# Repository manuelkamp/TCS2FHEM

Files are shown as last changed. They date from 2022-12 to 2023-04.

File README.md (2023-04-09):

# TCS2FHEM

If you have a TCS:Bus door intercom system and want to integrate it into your FHEM instance, this is a project for you. The goal of this project is to have a device, that connects the TCS:Bus intercom to FHEM. It should allow to trigger the dooropener and other functions (such as switching on the light) in FHEM. Also it should send events (like someone ringed the bell at the front door, or someone ringed the bell at the main door) to FHEM, so you can automate it (send notifications, interact...)  
## ATTENTION: THIS REPOSITORY IS A COPY AND WILL NOT BE UPDATED ON REGULAR BASIS. PLEASE GO TO https://git.kmpr.at/kamp/TCS2FHEM TO SEE THE LATEST CODE AND/OR SUBMIT PULL REQUESTS OR ISSUES!

## Hardware  
* [Raspberry Pico W](https://mk0.at/pico-w)  
* [Waveshare 2,23" OLED Display](https://mk0.at/waveshare-oled)  
* [4-Button Keypad](https://mk0.at/4-keypad)  
* PCB for your need (see kicad folder for examples)  
* 3D-printed Custom Case for Pico and Button Keypad and power circuit (see case_5v_PCB folder as an example)  

## Prereqisites
You need your PCB fully soldered with everything (you can use a Breadboard temporarily), including keypad and display. Load the Micropython firmware onto your Pico W. I used the v1.19.1-782-g699477d12 (2022-12-20).uf2. It is highly recommended to load the newest firmware from the official repository: https://micropython.org/download/rp2-pico-w/ - But you can use the one I used too, see firmware folder in this repository. Then upload all *.py files to the Pico W's root path (follow the instructions for configuration) and connect the TCS Bus lines accordingly. Finally plug in power (if not powered by TCS:Bus).

## Instructions/Setup
In the file configs.py set your configurations:  
country: your countrycode (AT=Austria, DE=Germany...) (2-digit string)  
ntp_host: set a ntp server (string url)  
gmt_offset: offset to gmt for your timezone in hours (int)  
auto_summertime: Enables changing to summertime (and back) automatically (True/False)  
disable_wifi_powersavingmode: Wifi powersavingmode is enabled per default. Set to true to disable powersavingmode for Wifi (True/False)  
api_port: Port on which the API is available (int)  
displayoff: Minutes after last action, display goes off automatically (int)  
log_incoming_bus_messages: Logs every incoming bus message, which is useful to find out relevant messages for initial setup (bool)  
log_housekeeping_days: Logfiles older than this value in days get deleted by housekeeping (int)  
frontdoor_ringing_message: The TCS:Bus message if someone rings the front door (list)  
door_ringing_message: The TCS:Bus message if someone rings the door (list)  
door_trigger_message: The TCS:Bus message to trigger the front door opener (list)  
light_trigger_message: The TCS:Bus message to trigger the light (list)  
tcs_message: The TCS:Bus message sent every 37 minutes from the TCS:Bus device to check devices - no action, just for filtering (list)  
api_client_ip: Only this IP is allowed to use the API. Leave blank to allow all connections from all IPs (string)  
fhem_door_ringed: URL of FHEM command, when the door is ringed (string)  
fhem_frontdoor_ringed: URL of FHEM command, when the front door is ringed (string)  

In the file secrets.py set your configurations:  
ssid: Wifi name (string)  
pw: Wifi password (string)  
api: API key (string)  

**Hint:** use `openssl rand -hex 20` to generate the api_key

## Wiring of Display  
```
OLED   =>    Pico  
VCC    ->    VSYS  
GND    ->    GND  
DIN    ->    11  
CLK    ->    10  
CS     ->    9  
DC     ->    8  
RST    ->    12  
SDA    ->    6  
SCL    ->    7   
```

## Wiring of 4-Button Keypad  
  

## Power circuit  
### Power from TCS Bus  
The power circuit allows you to run the Pico W directly from the TCS:Bus system's power. It also connects the bus to the Pico to read and write from it. The circuit files for KiCad are stored in the kicad subfolder 'power_from_tcs_bus' of this repo. You can order/print your own PCB with that files.  
  

### Power from 5V power source
The power circuit allows you to run the Pico W with a separate 5 Volt power source (f.e. a USB power adapter). It also connects the bus to the Pico to read and write from it. The circuit files for KiCad are stored in the kicad subfolder 'power_via_5v_source' of this repo. You can order/print your own PCB with that files.  
  

### Power from 9-24V power source
The power circuit allows you to run the Pico W with a separate power source from 9 Volt to 24 Volt. It also connects the bus to the Pico to read and write from it. The circuit files for KiCad are stored in the kicad subfolder 'power_via_9-24v_source' of this repo. You can order/print your own PCB with that files.  
  

## Networking  
Be sure that you give your Pico a static IP address on your router, so you know where the webservice is available and can set it up in FHEM.

## TCS2FHEM API  
You can configure the port, on which the API runs in configs.py in the 'api_port'-value. You also have to set an API-Key in secrets.py in the 'api'-value. Then you can call the API as follows:  
http://servername/api_key/command[/json]  

You can use the following commands:  
triggerdoor - Triggers the front door opener  
triggerlight - Triggers the light  
togglepartymode - Enables/disables the Party-Mode  
partymodeon - Sets Party-Mode enabled  
partymodeoff - Sets Party-Mode disabled  
partymodestate - Returns the state of the Party-Mode  
ping - Check if the API is up and running  
stats - Returns some stats of the device  
reboot - Reboots the device  
ringdoor - Sends "ring doorbell" message to TCS:Bus  
ringfrontdoor - Sends "ring front doorbell" message to TCS:Bus  

## FHEM API  

With the FHEM API you interconnect your FHEM instance with your TCS2FHEM device. It allows you for example control the door trigger via FHEM, or handle incoming TCS:Bus messages within FHEM to send you a notification or anything else. In this example configuration, we set up a HTTPMOD device in FHEM to control your TCS2FHEM device within FHEM, using the above explained API commands.  

### Example Setup of FHEMWEB

You need to give your TCS2FHEM device a static IP address within your network. Then you need to create a new FHEMWEB and configure it to work only with the static IP of your TCS2FHEM device without the csrfToken.  

```
define WEBapi FHEMWEB 8086 global
attr WEBapi csrfToken none
attr WEBapi allowfrom your-TCS2FHEM-static-IP|127.0.0.1
```

### Exampe of a HTTPMOD device in FHEM to control TCS2FHEM

This device is used to trigger actions from FHEM via the TCS2FHEM API. In this Example you can trigger the dooropener, the light and the builtin partymode of the TCS2FHEM device.  

```
define TCS2FHEM HTTPMOD 0
setuuid TCS2FHEM 63b875f4-f33f-1b7d-61d3-9101ee190fa5bae1
attr TCS2FHEM icon Todoist
attr TCS2FHEM room TCS
attr TCS2FHEM set01Name triggerDoor
attr TCS2FHEM set01NoArg 1
attr TCS2FHEM set01URL http://servername/api_key/triggerdoor
attr TCS2FHEM set02Name triggerLight
attr TCS2FHEM set02NoArg 1
attr TCS2FHEM set02URL http://servername/api_key/triggerlight
attr TCS2FHEM set03Name togglePartyMode
attr TCS2FHEM set03NoArg 1
attr TCS2FHEM set03URL http://servername/api_key/togglepartymode
attr TCS2FHEM webCmd triggerDoor:triggerLight:togglePartyMode
```

### Example of Notify and Dummy device in FHEM to send a message to your smartphone

This dummy device is used to represent the state. The state 'idle' means, there is no action. The state 'ringed' is set if someone rings your doorbell and the TCS2FHEM device sets it. The notify device in FHEM is used to see the change from idle to ringed, and you can perform your wanted action in FHEM.  

```
define TCS_Door dummy
setuuid TCS_Door 63a1c02e-f33f-1b7d-29b2-21917943a9d12101
attr TCS_Door room TCS
attr TCS_Door setList idle ringed
```

```
define n_TCS_Door notify TCS_Door:ringed set Talk msg Jemand hat an der Wohnungstür angeläutet;; set TCS_Door idle
setuuid n_TCS_Door 63a1c0c2-f33f-1b7d-fe89-1e89dde293580eb1
attr n_TCS_Door disabledAfterTrigger 10
attr n_TCS_Door room TCS
```

For this devices, the FHEM API Url that you need to use in TCS2FHEM setting 'fhem_door_ringed' would be:  
```
http://fhem-server:8086/fhem?cmd=set%20TCS_Door%20ringed&XHR=1
```

This works exactly the same for the TCS2FHEM settings 'fhem_frontdoor_ringed'.

### Example of Notify and Dummy device in FHEM for Partymode

If you decide to not use the builtin Partymode in your TCS2FHEM device, you can set up a Partymode in FHEM. This may be useful, if you want to trigger more actions as it would be possible with just the TCS2FHEM device.  

```
coming soon...
``` 

## Legal remarks
I am not affiliated to TCSAG and/or any of their brands and/or trademarks, nor do I have any business information on the proprietary TCS:Bus. I just reverse engineered it, to include my intercom system into my home automation and shared my research here. All Rights to the possible Trademark TCS:Bus and all things connected, remain untouched by this open source project.

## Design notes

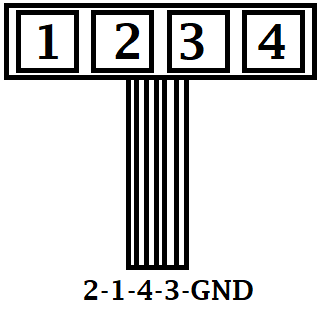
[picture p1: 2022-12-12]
docs/4-key-pad-connector.png

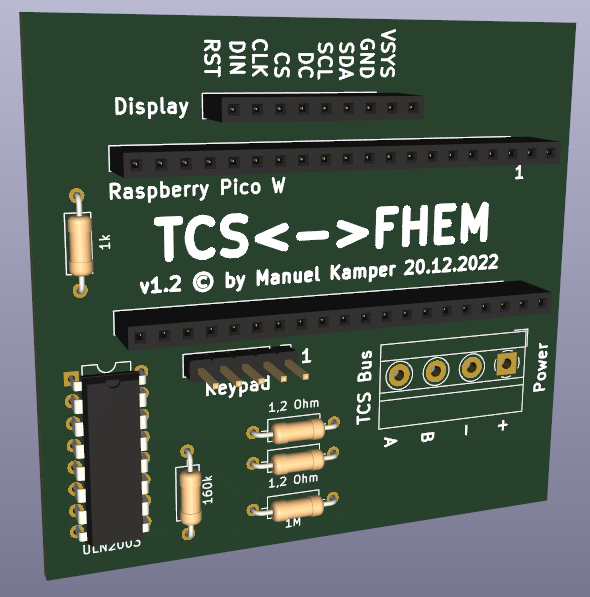
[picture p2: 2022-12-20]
docs/pico_tcs_5v.png

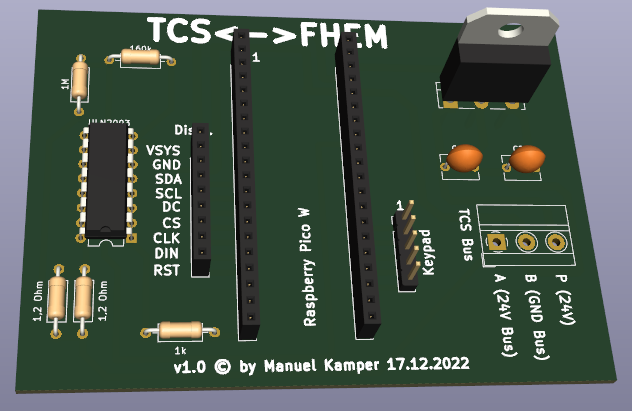
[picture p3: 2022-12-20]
docs/pico_tcs_bus.png

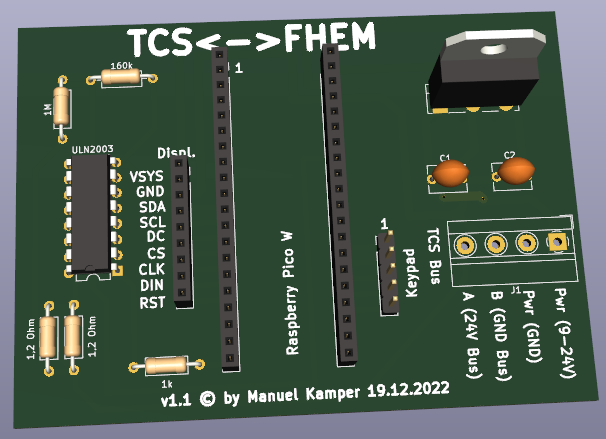
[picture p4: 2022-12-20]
docs/pico_tcs_9-24v.png

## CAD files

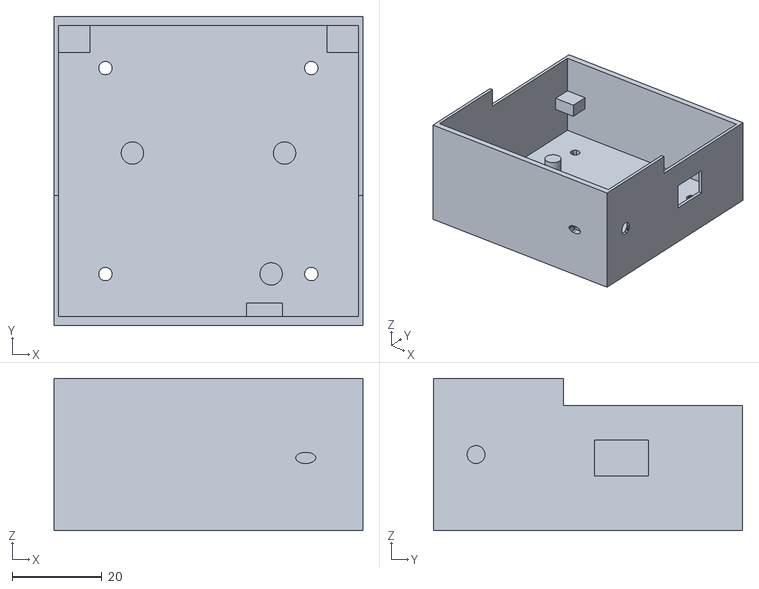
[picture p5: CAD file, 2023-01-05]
case_5v_PCB/case_base.stl
69.0 x 69.0 x 34.0

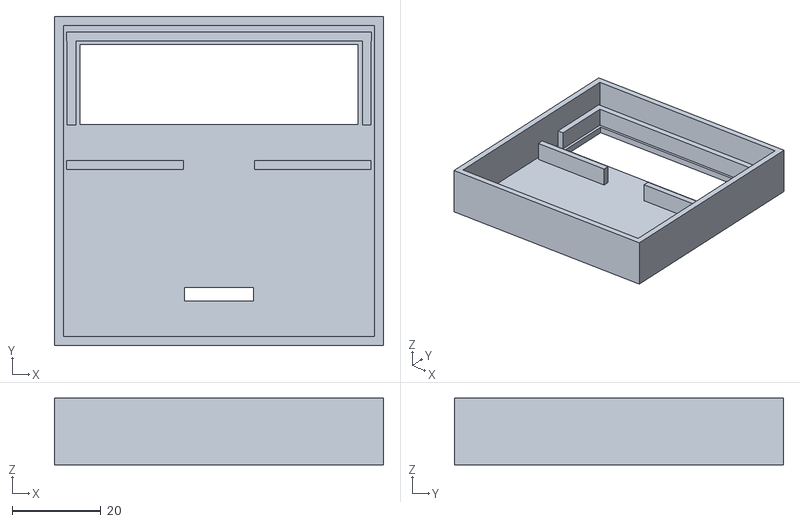
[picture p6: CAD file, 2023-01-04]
case_5v_PCB/case_plate.stl
74.0 x 74.0 x 15.0

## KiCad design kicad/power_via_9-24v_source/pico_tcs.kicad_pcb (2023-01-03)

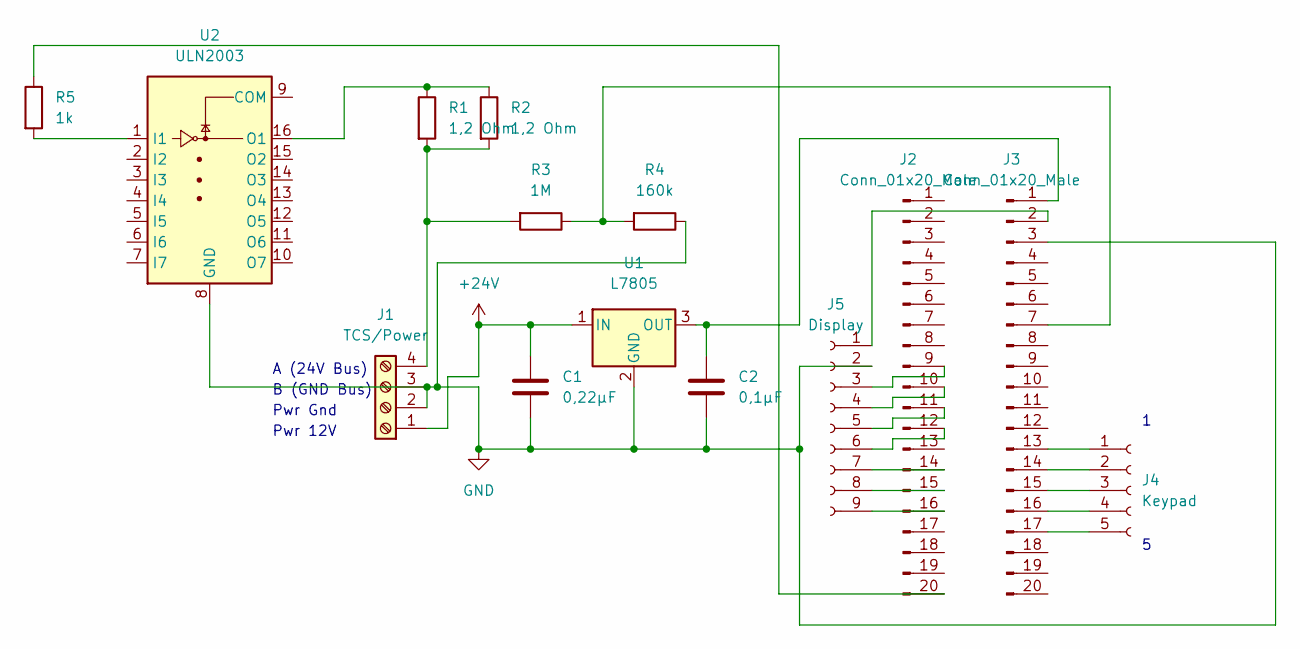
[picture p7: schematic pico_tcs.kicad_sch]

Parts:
C1: 0,22µF; C_Disc_D6.0mm_W4.4mm_P5.00mm
C2: 0,1µF; C_Disc_D6.0mm_W4.4mm_P5.00mm
J1: TCS/Power; TerminalBlock_MetzConnect_Type011_RT05504HBWC_1x04_P5.00mm_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
J2, J3: Conn_01x20_Male; PinSocket_1x20_P2.54mm_Vertical
J4: Keypad; PinHeader_1x05_P2.54mm_Vertical
J5: Display; PinSocket_1x09_P2.54mm_Vertical
R1, R2: 1,2 Ohm; R_Axial_DIN0207_L6.3mm_D2.5mm_P10.16mm_Horizontal
R3: 1M; R_Axial_DIN0207_L6.3mm_D2.5mm_P10.16mm_Horizontal
R4: 160k; R_Axial_DIN0207_L6.3mm_D2.5mm_P10.16mm_Horizontal
R5: 1k; R_Axial_DIN0207_L6.3mm_D2.5mm_P10.16mm_Horizontal
U1: L7805; TO-218-3_Vertical
U2: ULN2003; DIP-16_W7.62mm

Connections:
+24V: C1.1, J1.1, U1.1 (IN)
GND: C1.2, C2.2, J1.2, J1.3, J3.3, J5.2, R4.1, U1.2 (GND), U2.8 (GND)
unnamed: C2.1, J3.1, U1.3 (OUT)
unnamed: J1.4, R1.2, R2.2, R3.2
unnamed: J2.9, J5.3
unnamed: J2.10, J5.4
unnamed: J2.11, J5.5
unnamed: J2.12, J5.6
unnamed: J2.14, J5.7
unnamed: J2.15, J5.8
unnamed: J2.16, J5.9
unnamed: J2.20, R5.1
unnamed: J3.2, J5.1
unnamed: J3.7, R3.1, R4.2
unnamed: J3.13, J4.1
unnamed: J3.14, J4.2
unnamed: J3.15, J4.3
unnamed: J3.16, J4.4
unnamed: J3.17, J4.5
unnamed: R1.1, R2.1, U2.16 (O1)
unnamed: R5.2, U2.1 (I1)

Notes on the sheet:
Pwr Gnd
Pwr 12V
A (24V Bus)
B (GND Bus)

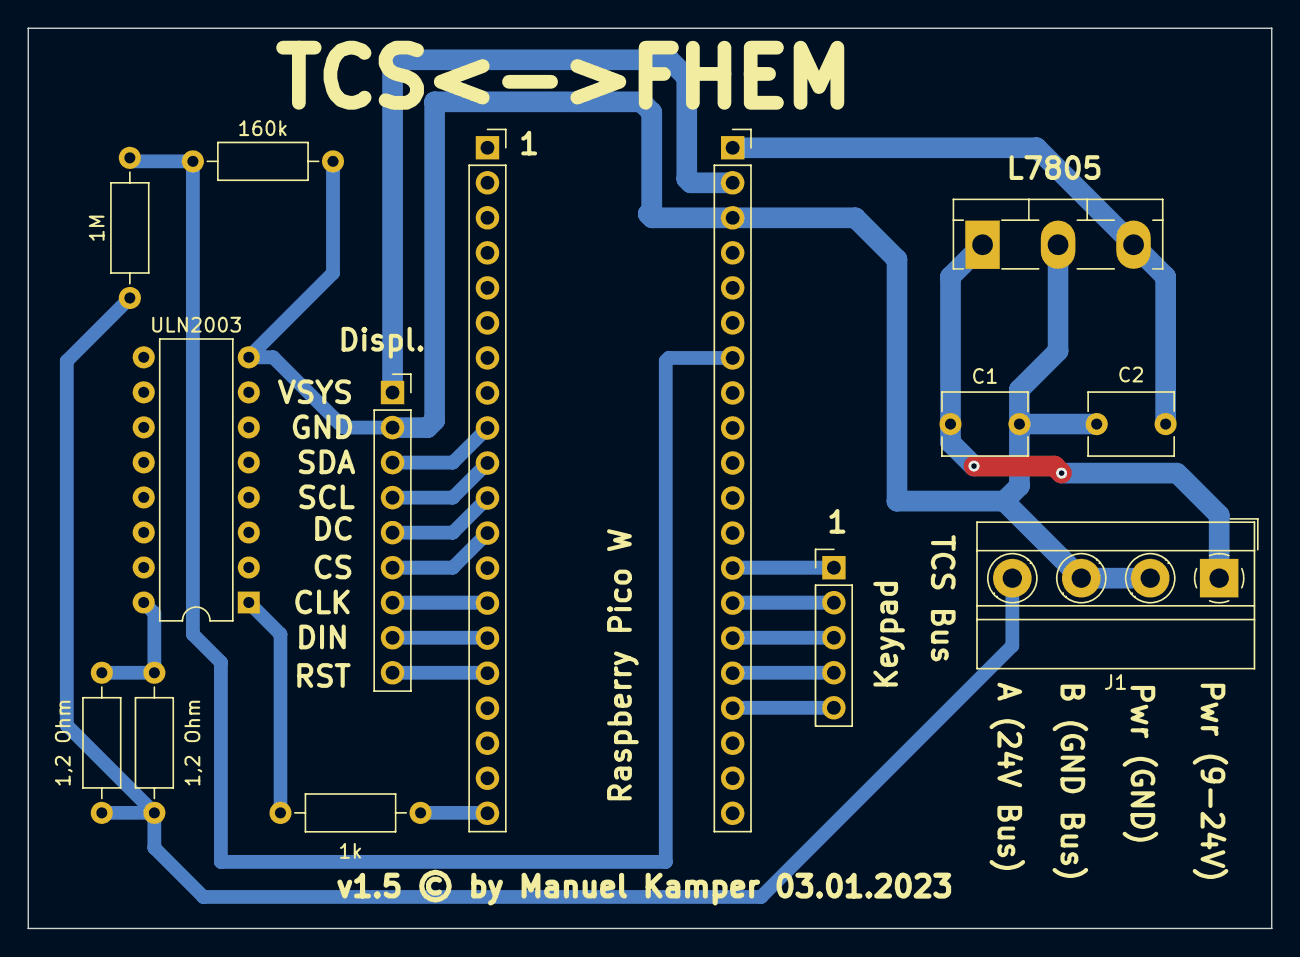
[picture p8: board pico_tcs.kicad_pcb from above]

Board: 2 copper layers, 90.2 x 65.3 mm, 14 parts (0 on the bottom side), 21 nets.

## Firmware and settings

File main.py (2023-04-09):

import rp2
import TimeUtils
import Logger
import Oled
import Networking
import NTP
import uasyncio as asyncio
import utime as time
import Keypad
import usocket as socket
import urequests as requests
from machine import ADC, Pin

from secrets import secrets
from configs import configs

rp2.country(configs['country'])
version = "0.9-beta"

Oled = Oled.Oled()
TimeUtils = TimeUtils.TimeUtils()
Logger = Logger.Logger(configs['log_housekeeping_days'])
Networking = Networking.Networking(Logger, secrets['ssid'], secrets['pw'])
NTP = NTP.NTP(Logger)
Keypad = Keypad.Keypad()

boottime = time.time()
lastActionTicks = 0
subscreen = 0
sc = 0
partyMode = False
displayOff = False
busline = ADC(28)
triggerline = Pin(15, Pin.OUT)
writerActive = False

# Checks if string is integer
def IsInt(possibleint):
    try:
        int(possibleint)
    except:
            return False
    else:
            return True

# Reboots the Pico W (f.e. in case of an error)
def Reboot():
    Logger.LogMessage("Performing Reboot")
    machine.reset()

# Calculates the uptime in hours and minutes
def Uptime():
    global boottime
    seconds = (time.time() - boottime) % (24 * 3600)
    hours = seconds // 3600
    seconds %= 3600
    minutes = seconds // 60
    seconds %= 60
    return "%d:%02d" % (hours, minutes)

# Shows text on the display
def ShowText(line1, line2, line3):
    Oled.fill(0x0000)
    Oled.text(line1,1,2,Oled.white)
    Oled.text(line2,1,12,Oled.white)
    Oled.text(line3,1,22,Oled.white)  
    Oled.show()

# Main method for display output
heartbeat = "H"
def BuildScreen():
    global subscreen, partyMode, lastActionTicks, displayOff, heartbeat
    if heartbeat == "H":
        heartbeat = " "
    else:
        heartbeat = "H"
    lastActionTicks += 1
    # after 10 Seconds of no activity, go back to main screen
    if (lastActionTicks >= 20):
        subscreen = 0
    # after X Minutes turn off the display
    if (lastActionTicks >= (configs['displayoff'] * 60 * 2)):
        displayOff = True
        ShowText("","","")
    else:
        if (subscreen == 0):
            ShowText("TCS<->FHEM " + PartyModeActive() + " " + Networking.IsWifiConnected() + " " + heartbeat + "", TimeUtils.DateTimeNow(), "Auf LiG PaM Chk")
        elif (subscreen == 1):
            ShowText("Eingangstuer", "getriggert", "            Ext")
        elif (subscreen == 2):
            ShowText("Licht am Gang", "getriggert", "            Ext")
        elif (subscreen == 3):
            ShowText("Party-Mode", ("aktiviert" if partyMode else "deaktiviert"), "            Ext")
        elif (subscreen == 4):
            ShowText("Hostname:", configs['hostname'], "Up  Dwn     Ext")
        elif (subscreen == 5):
            ShowText("MAC Address:", Networking.GetMACAddress(), "Up  Dwn     Ext")
        elif (subscreen == 6):
            ShowText("IP Address:", Networking.GetIPAddress(), "Up  Dwn     Ext")
        elif (subscreen == 7):
            ShowText("API key:", secrets['api'], "Up  Dwn     Ext")
        elif (subscreen == 8):
            ShowText("CPU Frequency:", str(machine.freq()/1000000) + " MHz", "Up  Dwn     Ext")
        elif (subscreen == 9):
            ShowText("Firmware vers.:", version, "Up  Dwn     Ext")
        elif (subscreen == 10):
            ShowText("Uptime (H:m):", Uptime(), "Up  Dwn     Ext")
        elif (subscreen == 11):
            ShowText("Perform", "reboot now", "Up  Dwn OK  Ext")
        else:
            ShowText("Error","Invalid Screen", "            Ext")

# Helper-method for the systemcheck-output on the display
def ShowSystemCheck(screen):
    global subscreen, sc
    if (screen == "start"):
        Logger.LogMessage("Showing Systemcheck")
        sc = 0
    elif (screen == "next"):
        sc = sc + 1
    else:
        sc = sc - 1
    if (sc > 7):
        sc = 0
    elif (sc < 0):
        sc = 7
    subscreen = sc + 4

# Activates/deactivates the party-mode
def TogglePartyMode():
    global subscreen, partyMode
    if (partyMode):
        partyMode = False
        ExternalAPI("partymode" + PartyModeState())
        Logger.LogMessage("Party-Mode off")
    else:
        partyMode = True
        ExternalAPI("partymode" + PartyModeState())
        Logger.LogMessage("Party-Mode on")
    subscreen = 3

# Sets the party-mode active/inactive
def SetPartyMode(newValue):
    global partyMode
    partyMode = newValue
    ExternalAPI("partymode" + PartyModeState())
    Logger.LogMessage("Setting Party-Mode via API to " + PartyModeState())

# Returns status of party-mode
def PartyModeState():
    global partyMode
    if (partyMode):
        return "enabled"
    else:
        return "disabled"

# Returns status symbol if party-mode is active
def PartyModeActive():
    global PartyMode
    if (partyMode):
        return "P"
    else:
        return " "

#####################################################################

# Helper-method to allow error handling and output in asyncio
def set_global_exception():
    def handle_exception(loop, context):
        Logger.LogMessage("Fatal error: " + str(context["exception"]))
        import sys
        sys.print_exception(context["exception"])
        sys.exit()
        Reboot()
    loop = asyncio.get_event_loop()
    loop.set_exception_handler(handle_exception)

# Main method for all the UI-handling
async def UiHandling():
    global interrupt_flag, lastActionTicks, displayOff, subscreen
    Logger.LogMessage("UI handling started")
    while True:
        BuildScreen()
        if Keypad.interrupt_flag is 1:
            Keypad.interrupt_flag = 0
            lastActionTicks = 0
            if (displayOff):
                displayOff = False
            else:
                Keypad.interrupt_flag = 0
                if (subscreen == 0):
                    if (Keypad.tastePressed == Keypad.taste1):
                        ShowSystemCheck("start")
                    elif (Keypad.tastePressed == Keypad.taste2):
                        TogglePartyMode()
                    elif (Keypad.tastePressed == Keypad.taste3):
                        subscreen = 2
                        Logger.LogMessage("Triggering Licht")
                        await TCSBusWriter(configs['light_trigger_message'])
                    elif (Keypad.tastePressed == Keypad.taste4):
                        subscreen = 1
                        Logger.LogMessage("Triggering Door")
                        await TCSBusWriter(configs['door_trigger_message'])
                    else:
                        Logger.LogMessage("Error: Invalid Button pressed!")
                elif (subscreen == 1 or subscreen == 2 or subscreen == 3):
                    if (Keypad.tastePressed == Keypad.taste1):
                        subscreen = 0
                elif (subscreen == 4 or subscreen == 5 or subscreen == 6 or subscreen == 7 or subscreen == 8 or subscreen == 9 or subscreen == 10 or subscreen == 11):
                    if (Keypad.tastePressed == Keypad.taste1):
                        subscreen = 0
                    elif (subscreen == 11 and Keypad.tastePressed == Keypad.taste2):
                        Reboot()
                    elif (Keypad.tastePressed == Keypad.taste3):
                        ShowSystemCheck("next")
                    elif (Keypad.tastePressed == Keypad.taste4):
                        ShowSystemCheck("prev")
                    else:
                        Logger.LogMessage("Error: Invalid Button pressed!")
                else:
                    if (Keypad.tastePressed == Keypad.taste1):
                        subscreen = 0
        await asyncio.sleep(0.5)

# Main method for the API
html = """<!DOCTYPE html>
<html>
    <head> <title>TCS<->FHEM</title> </head>
    <body> <h1>TCS<->FHEM</h1>
        <p>%s</p>
    </body>
</html>"""
json = """{ "TCS<->FHEM API":"%s" }"""
async def APIHandling(reader, writer):
    request_line = await reader.readline()
    while await reader.readline() != b"\r\n":
        pass
    request = str(request_line)
    try:
        request = request.split()[1]
    except IndexError:
        pass
    client_ip = writer.get_extra_info('peername')[0]
    Logger.LogMessage("API request: " + request + " - from client IP: " + client_ip)
    if (configs['api_client_ip'] != "") and (configs['api_client_ip'] != client_ip):
        Logger.LogMessage("Unauthorized client! Aborting API Handling now.")
        stateis = "<b>Error 401:</b> Client '" + client_ip + "' is not authorized to use the API!<br><br>Set authorized client IP in configs.py!"
        response = html % stateis
        writer.write('HTTP/1.0 401 Unauthorized\r\nContent-type: text/html\r\n\r\n')
    else:
        req = request.split('/')
        stateis = ""
        if (len(req) == 3 or len(req) == 4 or len(req) == 5):
            if (req[1] == secrets['api']):
                if (req[2] == "triggerdoor"):
                    Logger.LogMessage("Triggering Door")
                    await TCSBusWriter(configs['door_trigger_message'])
                    stateis = "Triggered front door opener"
                elif (req[2] == "triggerlight"):
                    Logger.LogMessage("Triggering Licht")
                    await TCSBusWriter(configs['light_trigger_message'])
                    stateis = "Triggered light"
                elif (req[2] == "togglepartymode"):
                    TogglePartyMode()
                    stateis = "Toggled Party-Mode"
                elif (req[2] == "partymodeon"):
                    SetPartyMode(True)
                    stateis = "Enabled Party-Mode"
                elif (req[2] == "partymodeoff"):
                    SetPartyMode(False)
                    stateis = "Disabled Party-Mode"
                elif (req[2] == "partymodestate"):
                    stateis = "Party-Mode is " + PartyModeState()
                elif (req[2] == "ping"):
                    stateis = "OK"
                elif (req[2] == "stats"):
                    stateis = "IP address: " + Networking.GetIPAddress() + "<br>MAC address: " + Networking.GetMACAddress() + "<br>Hostname: " + configs['hostname'] + "<br>API Port: " + str(configs['api_port']) + "<br>Uptime (h:m): " + Uptime() + "<br>Date/Time: " + TimeUtils.DateTimeNow() + "<br>Version: " + version + "<br>GMT Timezone Offset (hours): " + str(configs['gmt_offset']) + "<br>Auto summertime: " + str(configs['auto_summertime']) + "<br>Display off time (mins): " + str(configs['displayoff']) + "<br>Log incoming bus messages: " + str(configs['log_incoming_bus_messages']) + "<br>Housekeep logfiles after days: " + str(configs['log_housekeeping_days']) + "<br>Message 'Front door ringing': " + str(configs['frontdoor_ringing_message']) + "<br>Message 'Door ringing': " + str(configs['door_ringing_message']) + "<br>Message 'Door opener triggered': " + str(configs['door_trigger_message']) + "<br>Message 'Light triggered': " + str(configs['light_trigger_message']) + "<br>CPU frequency (MHz): " + str(machine.freq()/1000000)
                elif (req[2] == "reboot"):
                    stateis = "Rebooting device now..."
                    Reboot()
                elif (req[2] == "ringdoor"):
                    stateis = "Ringing doorbell"
                    await TCSBusWriter(configs['door_ringing_message'])
                elif (req[2] == "ringfrontdoor"):
                    stateis = "Ringing front doorbell"
                    await TCSBusWriter(configs['frontdoor_ringing_message'])
                elif (req[2] == "logs"):
                    if (len(req) >= 4 and req[3] != "json"):
                        if (IsInt(req[3])):
                            stateis = Logger.LastLogs(int(req[3]))
                        else:
                            stateis = "<b>Error:</b> Parameter for log length not an integer!"
                    else:
                        stateis = Logger.LastLogs(50)
                else:
                    stateis = "<b>Error:</b> Unknown command!"
            else:
                stateis = "<b>Error:</b> API key is invalid!"
            if ((len(req) == 4 and req[3] == "json") or (len(req) == 5 and req[4] == "json")):
                response = json % stateis
                writer.write('HTTP/1.0 200 OK\r\nContent-type: text/json\r\n\r\n')
            else:
                response = html % stateis
                writer.write('HTTP/1.0 200 OK\r\nContent-type: text/html\r\n\r\n')
        else:
            stateis = "<b>Error 400:</b> Invalid usage of API!<br><br><u>Usage:</u> http://servername/api_key/command[/json]<br><br><u>Commands:</u><ul><li>triggerdoor</li><li>triggerlight</li><li>togglepartymode</li><li>partymodeon</li><li>partymodeoff</li><li>partymodestate</li><li>ping</li><li>stats</li><li>reboot</li><li>ringdoor</li><li>ringfrontdoor</li></ul><br><u>API Key:</u> set 'api' in secrets.py file."
            response = html % stateis
            writer.write('HTTP/1.0 400 Bad Request\r\nContent-type: text/html\r\n\r\n')
    writer.write(response)
    await writer.drain()
    await writer.wait_closed()

microsFlanke = 0
def microsSeitLetzterFlanke():
    global microsFlanke
    return time.ticks_us() - microsFlanke

# Main method for the TCS:Bus reader
async def TCSBusReader():
    global busline, microsFlanke, partyMode, writerActive
    zustand = False
    Logger.LogMessage("TCS Busreader started")
    message = []
    while True:
        if not writerActive:
            busValue = busline.read_u16()
            val = 1
            if (busValue >= 30000): #voltage on TCS:Bus 0...65535
                val = 1
            else:
                val = 0
            #measure voltage changes and time in between
            dauer = microsSeitLetzterFlanke()
            if (dauer > 10000) and (message): #handle recieved message, and reset message
                message.pop(0) #remove first timing, because we do not need it
                for i in range(len(message)): #encode bus message (lazy, because the TCS:Bus is not as precise as we are ;) )
                    if (message[i] >= 1000 and message[i] <= 2999):
                        message[i] = 0
                    elif (message[i] >= 3000 and message[i] <= 4999):
                        message[i] = 1
                    elif (message[i] >= 5000 and message[i] <= 6999):
                        message[i] = 2
                    elif (message[i] >= 7000): #this may be an invalid message bit, but for not having numbers like '7543', we encode all this to '3'
                        message[i] = 3
                if (message == configs['light_trigger_message']):
                    if (configs['log_incoming_bus_messages']):
                        Logger.LogMessage("Incoming TCS:Bus message for triggering light: " + str(message))
                    #nothing else to do
                    pass
                elif (message == configs['door_trigger_message']):
                    if (configs['log_incoming_bus_messages']):
                        Logger.LogMessage("Incoming TCS:Bus message for door trigger: " + str(message))
                    #nothing else to do
                    pass
                elif (message == configs['tcs_message']):
                    if (configs['log_incoming_bus_messages']):
                        Logger.LogMessage("Incoming TCS:Bus message from device: " + str(message))
                    #nothing else to do
                    pass
                elif (message == configs['door_ringing_message']):
                    if (configs['log_incoming_bus_messages']):
                        Logger.LogMessage("Incoming TCS:Bus message for door ringing: " + str(message))
                    await ExternalAPI("doorbell")
                elif (message == configs['frontdoor_ringing_message']):
                    if (configs['log_incoming_bus_messages']):
                        Logger.LogMessage("Incoming TCS:Bus message for frontdoor ringing: " + str(message))
                    if (partyMode):
                        asyncio.sleep(1)
                        Logger.LogMessage("Triggering Door and Light for Party-Mode")
                        await TCSBusWriter(configs['door_trigger_message'])
                        asyncio.sleep(1)
                        await TCSBusWriter(configs['light_trigger_message'])
                    await ExternalAPI("frontdoorbell")
                else:
                    if (configs['log_incoming_bus_messages']):
                        Logger.LogMessage("Unknown TCS:Bus message: " + str(message))
                message = []
            else:
                if (val == 0 and zustand == False):
                    message.append(dauer)
                    zustand = True
                    microsFlanke = time.ticks_us()
                if (val == 1 and zustand == True):
                    message.append(dauer)
                    zustand = False
                    microsFlanke = time.ticks_us()
            await asyncio.sleep(0)

# Main method for the TCS:Bus writer
async def TCSBusWriter(message):
    global writerActive
    if (message):
        busMessage = list(message)
        writerActive = True
        for i in range(len(busMessage)): #decode message
            busMessage[i] = int((busMessage[i] + 1) * 2000)
        #start sending message
        sendZero = True
        triggerline.on()
        for i in range(len(busMessage)):
            time.sleep_us(busMessage[i])
            sendZero = not sendZero
            if sendZero:
                triggerline.on()
            else:
                triggerline.off()
        #finally end sending message
        triggerline.off()
        writerActive = False

# Main method for external API (=FHEM)
async def ExternalAPI(action):
    Logger.LogMessage("External API action: " + action)
    if (action == "doorbell"):
        if (configs['fhem_door_ringed'] is not ""):
            response = requests.get(configs['fhem_door_ringed'])
            response.close()
        else:
            Logger.LogMessage("Warning: No fhem_door_ringed setting!")
    elif (action == "frontdoorbell"):
        if (configs['fhem_frontdoor_ringed'] is not ""):
            response = requests.get(configs['fhem_frontdoor_ringed'])
            response.close()
        else:
            Logger.LogMessage("Warning: No fhem_frontdoor_ringed setting!")
    else:
        Logger.LogMessage("Error: Unknown ExternalAPI action!")
    pass

# Main method for daily housekeeping
async def Housekeeper():
    Logger.LogMessage("Housekeeper started")
    while True:
        Logger.LogMessage("Housekeeper is performing actions")
        Logger.Housekeeping()
        Logger.LogMessage("Housekeeper is performing NTP sync")
        NTP.SetRTCTimeFromNTP(configs['ntp_host'], configs['gmt_offset'], configs['auto_summertime'])
        Logger.LogMessage("Housekeeper has finished its jobs")
        await asyncio.sleep(86400)

# Main entry point after booting
async def Main():
    set_global_exception()
    Logger.LogMessage("Entering MainLoop")
    boottime = time.time()
    loop = asyncio.get_event_loop()
    ShowText("Booting [3/3]", "API Setup: key", secrets['api'])
    Logger.LogMessage("Setting up API on port " + str(configs['api_port']) + " with key " + secrets['api'])
    loop.create_task(asyncio.start_server(APIHandling, Networking.GetIPAddress(), configs['api_port']))
    Logger.LogMessage("API started")
    ShowText("TCS<->FHEM", "Firmware:", version)
    Logger.LogMessage("Booting complete with Firmware " + version)
    loop.create_task(UiHandling())
    loop.create_task(TCSBusReader())
    loop.create_task(Housekeeper())
    loop.run_forever()

# Booting the device
def Boot():
    ShowText("Booting [1/3]", "Conn. Wifi:", secrets['ssid'] + "...")
    ShowText("Booting [1/3]", "Conn. Wifi: MAC", Networking.GetMACAddress())
    Networking.Connect(configs['disable_wifi_powersavingmode'])
    if (Networking.Status()):
        ShowText("Booting [1/3]", "Conn. Wifi: IP", Networking.GetIPAddress())
        ShowText("Booting [2/3]", "NTP time:", configs['ntp_host'])
        if (NTP.SetRTCTimeFromNTP(configs['ntp_host'], configs['gmt_offset'], configs['auto_summertime'])):
            Logger.DisableTempLogfile()
        ShowText("Booting [2/3]", "NTP time:", TimeUtils.DateTimeNow())
    else:
        ShowText("Booting [1/3]", "Conn. Wifi:", "ERROR!")
        time.sleep(3)
        Reboot()

#####################################################################
        
Boot()
try:
    asyncio.run(Main())
except KeyboardInterrupt:
    Logger.LogMessage("Shutdown.")
    Oled.fill(0x0000)
    Oled.show()
finally:
    asyncio.new_event_loop()

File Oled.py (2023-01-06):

from machine import Pin,SPI
import framebuf
import time

DC = 8
RST = 12
MOSI = 11
SCK = 10
CS = 9

class Oled(framebuf.FrameBuffer):
    def __init__(self):
        self.width = 128
        self.height = 32
        
        self.cs = Pin(CS,Pin.OUT)
        self.rst = Pin(RST,Pin.OUT)
        
        self.cs(1)
        self.spi = SPI(1)
        self.spi = SPI(1,1000_000)
        self.spi = SPI(1,10000_000,polarity=0, phase=0,sck=Pin(SCK),mosi=Pin(MOSI),miso=None)
        self.dc = Pin(DC,Pin.OUT)
        self.dc(1)
        self.buffer = bytearray(self.height * self.width // 8)
        super().__init__(self.buffer, self.width, self.height, framebuf.MONO_VLSB)
        self.init_display()
        
        self.white =   0xffff
        self.black =   0x0000
        
    def write_cmd(self, cmd):
        self.cs(1)
        self.dc(0)
        self.cs(0)
        self.spi.write(bytearray([cmd]))
        self.cs(1)

    def write_data(self, buf):
        self.cs(1)
        self.dc(1)
        self.cs(0)
        self.spi.write(bytearray([buf]))
        self.cs(1)

    def init_display(self):
        """Initialize dispaly"""  
        self.rst(1)
        time.sleep(0.001)
        self.rst(0)
        time.sleep(0.01)
        self.rst(1)
        
        self.write_cmd(0xAE)#turn off OLED display*/
    
        self.write_cmd(0x04)#turn off OLED display*/

        self.write_cmd(0x10)#turn off OLED display*/	
    
        self.write_cmd(0x40)#set lower column address*/ 
        self.write_cmd(0x81)#set higher column address*/ 
        self.write_cmd(0x80)#--set start line address  Set Mapping RAM Display Start Line (0x00~0x3F, SSD1305_CMD)
        self.write_cmd(0xA1)#--set contrast control register
        self.write_cmd(0xA6)# Set SEG Output Current Brightness 
        self.write_cmd(0xA8)#--Set SEG/Column Mapping	
        self.write_cmd(0x1F)#Set COM/Row Scan Direction   
        self.write_cmd(0xC8)#--set normal display  
        self.write_cmd(0xD3)#--set multiplex ratio(1 to 64)
        self.write_cmd(0x00)#--1/64 duty
        self.write_cmd(0xD5)#-set display offset	Shift Mapping RAM Counter (0x00~0x3F) 
        self.write_cmd(0xF0)#-not offset
        self.write_cmd(0xD8) #--set display clock divide ratio/oscillator frequency
        self.write_cmd(0x05)#--set divide ratio, Set Clock as 100 Frames/Sec
        self.write_cmd(0xD9)#--set pre-charge period
        self.write_cmd(0xC2)#Set Pre-Charge as 15 Clocks & Discharge as 1 Clock
        self.write_cmd(0xDA) #--set com pins hardware configuration 
        self.write_cmd(0x12)   
        self.write_cmd(0xDB) #set vcomh
        self.write_cmd(0x08)#Set VCOM Deselect Level
        self.write_cmd(0xAF); #-Set Page Addressing Mode (0x00/0x01/0x02)

    def show(self):
        for page in range(0,4):
            self.write_cmd(0xb0 + page)
            self.write_cmd(0x04)
            self.write_cmd(0x10)
            self.dc(1)
            for num in range(0,128):
                self.write_data(self.buffer[page*128+num])

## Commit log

2022-12-11 „README.md“ ändern
2022-12-12 Dateien hochladen nach „docs“
2022-12-12 Dateien hochladen nach „“
2022-12-12 Dateien hochladen nach „“
    implemented #5
2022-12-17 Dateien hochladen nach „kicad“
    [pico_tcs.kicad_pcb, pico_tcs.kicad_sch]
2022-12-18 „secrets.py“ ändern
2022-12-20 „docs/pico_tcs.png“ löschen
2022-12-20 „kicad/pico_tcs.kicad_sch“ löschen
    [pico_tcs.kicad_sch]
2022-12-20 „kicad/pico_tcs.kicad_pro“ löschen
2022-12-20 „kicad/pico_tcs.kicad_prl“ löschen
2022-12-20 „kicad/pico_tcs.kicad_pcb“ löschen
    [pico_tcs.kicad_pcb]
2022-12-20 „kicad/fp-info-cache“ löschen
2022-12-20 Dateien hochladen nach „kicad/power_from_tcs_bus“
    [pico_tcs.kicad_pcb, pico_tcs.kicad_sch]
2022-12-20 Dateien hochladen nach „kicad/power_via_5v_source“
    [pico_tcs.kicad_pcb, pico_tcs.kicad_sch]
2022-12-20 Dateien hochladen nach „kicad/power_via_9-24v_source“
    [pico_tcs.kicad_pcb, pico_tcs.kicad_sch]
2023-01-03 Dateien hochladen nach „kicad/power_from_tcs_bus“
    fixed bug in connection between display and pico
    [pico_tcs.kicad_pcb, pico_tcs.kicad_sch]
2023-01-03 Dateien hochladen nach „firmware“
2023-01-03 fixed #18
    create folder "logs" if it does not exist
    [Logger.py]
2023-01-03 „case_base.stl“ löschen
    [case_base.stl]
2023-01-03 „case_plate.stl“ löschen
    [case_plate.stl]
2023-01-03 Dateien hochladen nach „case_5v_PCB“
    [case_base.stl, case_plate.stl]
2023-01-04 improved plate with display holder and relocated keypad-hole and thicker case-walls
    [case_plate.stl]
2023-01-04 improved case base
    [case_base.stl]
2023-01-04 reversed keypad button order to fit new case design (keypad upside down)
    [Keypad.py]
2023-01-06 implemented basic bus reader #13
    missing triggering of external api
    [main.py]

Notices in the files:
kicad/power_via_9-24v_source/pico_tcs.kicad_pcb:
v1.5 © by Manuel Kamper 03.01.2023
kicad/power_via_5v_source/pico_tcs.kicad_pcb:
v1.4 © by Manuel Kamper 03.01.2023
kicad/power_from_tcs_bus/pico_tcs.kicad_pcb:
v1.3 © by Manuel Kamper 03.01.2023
